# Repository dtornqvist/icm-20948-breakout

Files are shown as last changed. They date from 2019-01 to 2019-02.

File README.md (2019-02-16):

# Breakout board for ICM-20948 with i2c

This repository contains a breakout board for the 9-DOF Inertial Measurement Unit (IMU) from TDK, ICM-20948 ([data sheet](https://www.invensense.com/wp-content/uploads/2016/06/DS-000189-ICM-20948-v1.3.pdf)). The i2c communication pins and the interrupt pin has external connection. The board is designed for 3.3v power supply, as the IMU requires 1.8v IO-levels there is a voltage level translator that translate IO-levels to/from the supply voltage. As the voltage level translator contains internal pull up resistors, there is no need to have extra pull up resistors on the IO-lines.

### Note
I have done some initial tests of this board and it seems to work just fine. I have also done an [Arduino library](https://github.com/dtornqvist/icm-20948-arduino-library) for getting the data out.

## Bill of Material

- U1: NCP563SQ18T1G, 1.8v voltage regulator ([data sheet](https://www.onsemi.com/pub/Collateral/NCP562-D.PDF))
- U2: NTS0104, voltage level translator, ([data sheet](https://www.nxp.com/docs/en/data-sheet/NTS0104.pdf))
- U3: ICM-20948, IMU, ([data sheet](http://www.invensense.com/wp-content/uploads/2016/06/DS-000189-ICM-20948-v1.3.pdf))
- C1, C2, C3: Capacitor 0402, 0.1uF
- C4, C5: Capacitor 0402, 1.0uF
- J1, J2: 3-pin 0.1'/2.54mm connectors

## Repository Contents
- /Hardware - Eagle design files (.brd, .sch)

## License Information
The hardware is released under [Creative Commons Share-alike 3.0](http://creativecommons.org/licenses/by-sa/3.0/).

## Credits
Special thanks to [Kris Winer](https://github.com/kriswiner) for all helpful comments during the design process.

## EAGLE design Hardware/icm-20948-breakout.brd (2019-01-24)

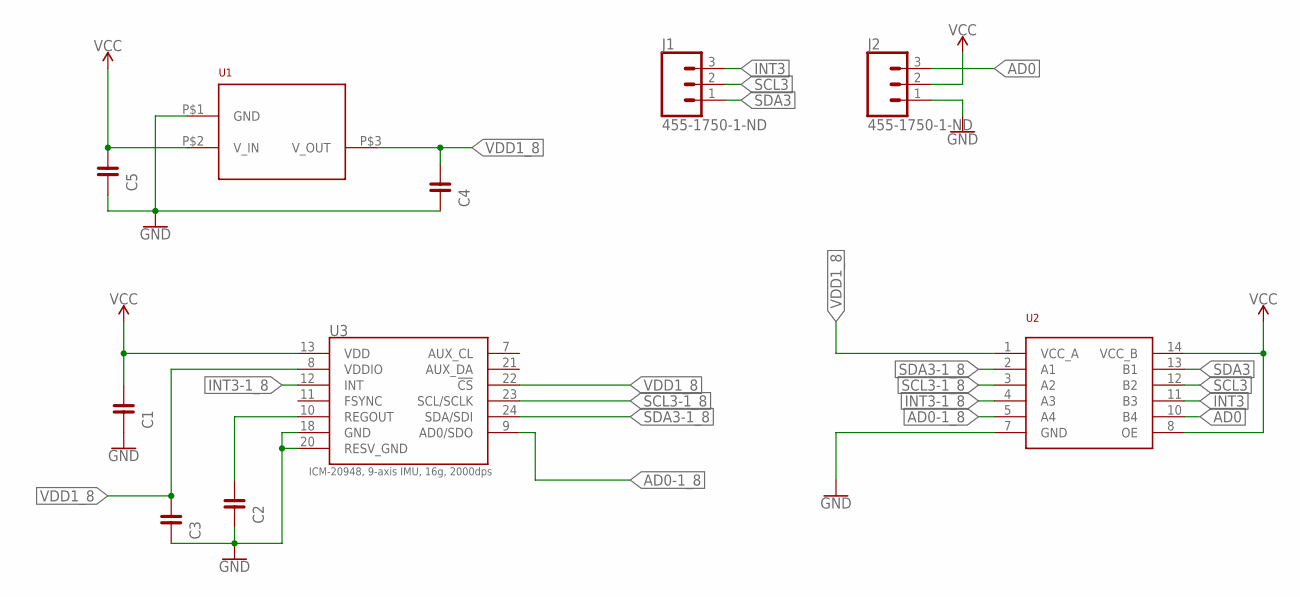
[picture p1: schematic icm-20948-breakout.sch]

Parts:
C1, C2, C3: 0.1uF; 0402
C4, C5: 1.0uF; 0402
J1, J2: 455-1750-1-ND; 1X03
U1: NCP563; SC−82AB
U2: NTS0104; SOT762-1
U3: ICM-20948; SPARKFUN-SENSORS_MPU-9250

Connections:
AD0: J2.3, U2.10 (B4)
AD0-1_8: U2.5 (A4), U3.9 (AD0/SDO)
GND: C1.P$2 (2), C2.P$2 (2), C3.P$2 (2), C4.P$2 (2), C5.P$2 (2), J2.1, U1.P$1 (GND), U2.7 (GND), U3.18 (GND), U3.20 (RESV_GND)
INT3: J1.3, U2.11 (B3)
INT3-1_8: U2.4 (A3), U3.12 (INT)
unnamed: C2.P$1 (1), U3.10 (REGOUT)
SCL3: J1.2, U2.12 (B2)
SCL3-1_8: U2.3 (A2), U3.23 (SCL/SCLK)
SDA3: J1.1, U2.13 (B1)
SDA3-1_8: U2.2 (A1), U3.24 (SDA/SDI)
VCC: C1.P$1 (1), C5.P$1 (1), J2.2, U1.P$2 (V_IN), U2.8 (OE), U2.14 (VCC_B), U3.13 (VDD)
VDD1_8: C3.P$1 (1), C4.P$1 (1), U1.P$3 (V_OUT), U2.1 (VCC_A), U3.8 (VDDIO), U3.22 (!CS)

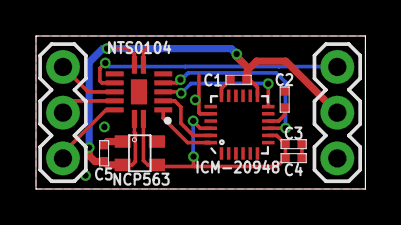
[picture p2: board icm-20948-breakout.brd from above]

Board: 2 copper layers, 18.3 x 8.5 mm, 10 parts (0 on the bottom side), 12 nets.

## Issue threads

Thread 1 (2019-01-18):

Minor Issue with Level Translator

CZEMacLeod, 2019-01-18:
First: Love this.
Absolutely excellent [README.md](https://github.com/dtornqvist/icm-20948-breakout/blob/master/README.md)

Looking at the spec sheet for the [NTS0104](https://www.nxp.com/docs/en/data-sheet/NTS0104.pdf) it says

> [1] The A and B sides of an unused I/O pair must be held in the same state, both at VCCI or both at GND.

(Page 6 / Section 10 - Recommended operating conditions)

Therefore I suggest grounding the unused A4/B4 pins.

dtornqvist, 2019-01-18:
Well spotted! Thanks! I just pushed a commit fixing that.

drcpattison, 2019-01-18:
Given that the voltage level translator contains internal pull up resistors, it should be possible to eliminate R1 by connecting nCS to A4 and B4 to VCC (instead of grounding them).

dtornqvist, 2019-01-20:
Thanks drcpattison! I updated the design accordingly. Now I have second thoughts. Wouldn't this be equivalent to connecting nCS directly to 1.8v? The data sheet says it should be pulled to 1.8v, but not attached directly.

The spec sheet for the NTS0104, section 14.7 says all ports contains 10k pull-up resistors. So, I think it should be enough to connect nCS to A4 and leave B4 unconnected. On the other hand, as CZEMacLeod pointed out, any unused ports should be connected to either ground or VCCI. I don't understand why this is necessary if they have pull-ups...

drcpattison, 2019-01-29:
No problem, just to clarify if you look at Fig. 11 of the NTS0104 datasheet you can see that both A & B sides are connected to their respective VCC pins via a 10k pull-up so they are not connected directly (ie equivalent to what you originally designed). The other (higher voltage) side needs to be pulled high so the nCS (negated Chip Select) is disabled which is a requirement for I2C operation. I think your latest design which uses the spare pins to access the INT/AD0 pins is preferred though.

I'm not sure why it says all pins need to be connected but one possibility is having floating pins could confuse the edge detectors, leading to a higher power consumption than specified as a lot more switching would occur than if they were held to a specific voltage - that's just a guess though.

I've spotted one other thing you may want to consider, Fig. 10 of the NTS0104 datasheet (typical operating circuit) shows 1.0uF and 0.1uF bypass capacitors connected to the high voltage side. Currently it appears you only have a 1.0uF cap connected.

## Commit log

2019-01-18 Initial commit.
    [icm-20948-breakout.brd, icm-20948-breakout.sch]
2019-01-18 Connected unused io pins on the level translator to ground.
    [icm-20948-breakout.brd, icm-20948-breakout.sch]
2019-01-20 Redesign after comments. Changed footprints of capacitors. Removed routing under ICS. Connected nCS to level switcher to avoid a resistor. Added solder jumper to set address. Added ground planes on b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
    [icm-20948-breakout.brd, icm-20948-breakout.sch]
2019-01-20 Updates to meet the design rules of OSH Park. However, still lots of clearance issues with the ICM-footprint.
    [icm-20948-breakout.brd]
2019-01-21 Updated ICM footprint. The design rules of OSH Park are now met.
    [icm-20948-breakout.brd, icm-20948-breakout.sch]
2019-01-21 Fixed text layouts.
    [icm-20948-breakout.brd, icm-20948-breakout.sch]
2019-01-21 Added gitignore and minor updates.
    [icm-20948-breakout.brd]
2019-01-22 Remake to fit 0.7 inch width.
    [icm-20948-breakout.brd]
2019-01-22 Changed DRC settings to get vias covered.
    [icm-20948-breakout.brd]
2019-01-23 Went back to 0.6 inch width. Took away ground plane under icm. Added AD0 as an output pin with pull-up and therefore removed solder jumper.
    [icm-20948-breakout.brd, icm-20948-breakout.sch]
2019-01-23 Added label for the AD0 pin.
    [icm-20948-breakout.brd]
2019-01-24 Updated text sizes.
    [icm-20948-breakout.brd]
2019-02-16 Updated readme with info about Arduino library.

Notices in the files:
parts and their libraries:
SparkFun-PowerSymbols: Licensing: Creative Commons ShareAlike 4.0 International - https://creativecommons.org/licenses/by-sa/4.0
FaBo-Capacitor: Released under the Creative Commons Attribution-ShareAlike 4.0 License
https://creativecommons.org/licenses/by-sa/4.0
